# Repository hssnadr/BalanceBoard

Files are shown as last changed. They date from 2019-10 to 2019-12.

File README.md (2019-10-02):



# BalanceBoard
The Balance board demo project is part of the Movuino project: http://www.movuino.com/  
Project presentation: http://www.movuino.com/index.php/portfolio/balance-board/

## Set-up
* Download and install Movuino/Movuina: www.movuino.com
* Follow the tutorial to receive the data from your sensor: http://www.movuino.com/index.php/quick-start/
* Install PureData Vanilla from: www.puredata.info
* Into PureData, go to: Help/Find Externals
* Search for "MrPeach" library, it's used to receive the messages from Movuina through OSC communication
* Install and restart PureData
* Launch the BalanceBoard_Application.pd patch

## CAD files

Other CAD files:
01_MakingRessources/CAO/MovuinoCase_WorkFile.CATPart

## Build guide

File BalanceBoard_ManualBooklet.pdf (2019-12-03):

# BALANCE BOARD

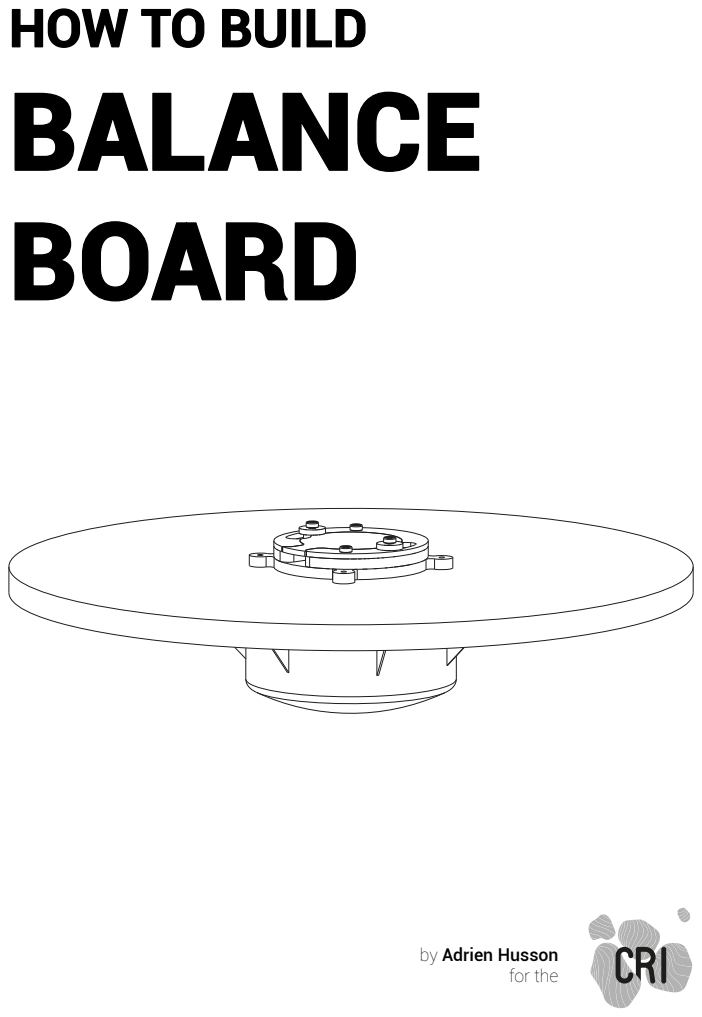
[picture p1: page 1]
for the

HOW TO BUILD

by Adrien Husson

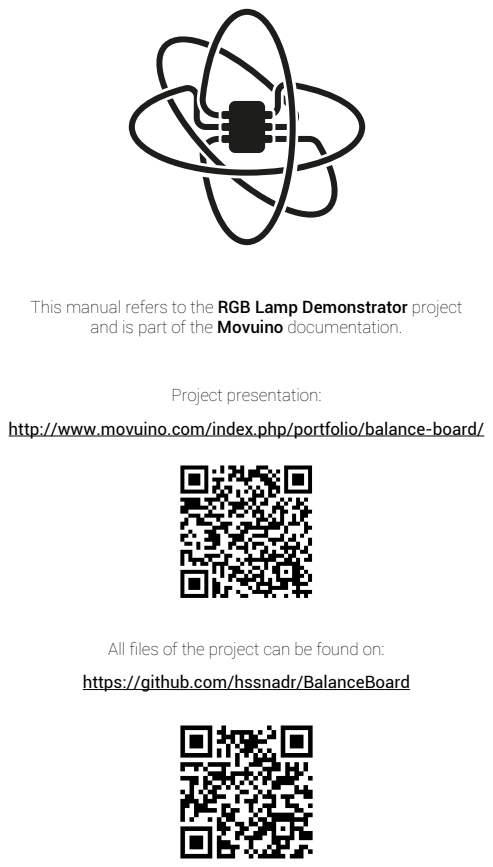
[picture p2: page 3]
Project presentation:

This manual refers to the RGB Lamp Demonstrator project
and is part of the Movuino documentation.

http://www.movuino.com/index.php/portfolio/balance-board/

All files of the project can be found on:
https://github.com/hssnadr/BalanceBoard

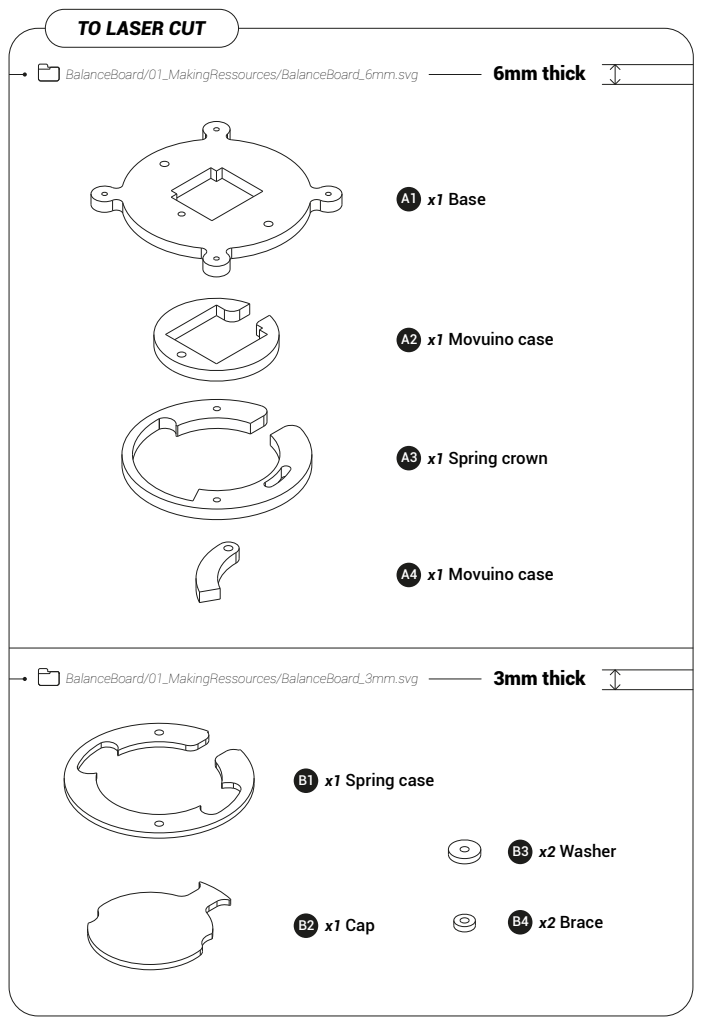
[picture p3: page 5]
3mm thick; BalanceBoard/01_MakingRessources/BalanceBoard_6mm.svg; A1 x1 Base; A2 x1 Movuino case; A4 x1 Movuino case; B1 x1 Spring case; B3 x2 Washer; B2 x1 Cap; B4 x2 Brace; A3 x1 Spring crown; 6mm thick; BalanceBoard/01_MakingRessources/BalanceBoard_3mm.svg

TO LASER CUT

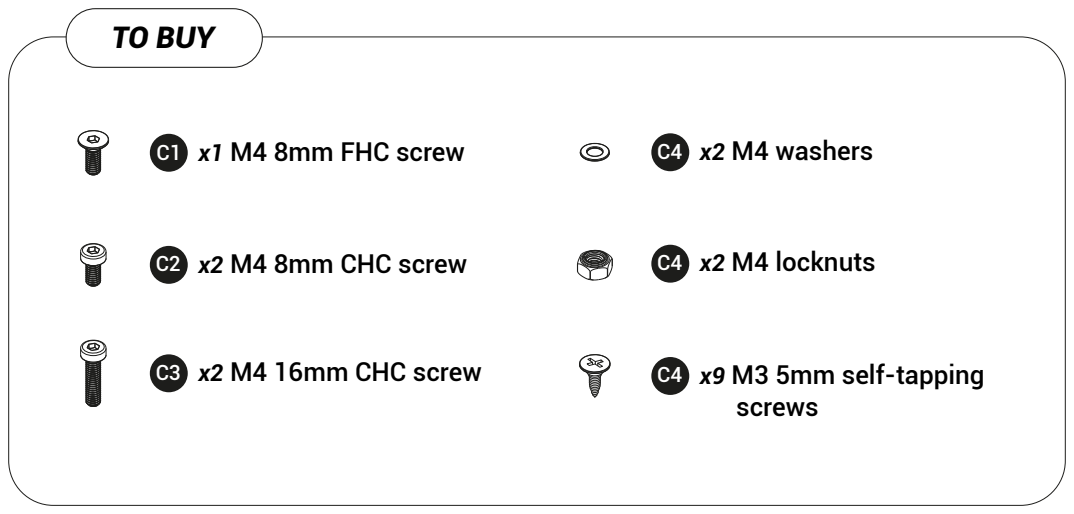
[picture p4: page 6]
TO BUY; C1 x1 M4 8mm FHC screw; C2 x2 M4 8mm CHC screw; C3 x2 M4 16mm CHC screw; C4 x2 M4 washers; C4 x2 M4 locknuts; x9 M3 5mm self-tapping screws

# ASSEMBLY

1

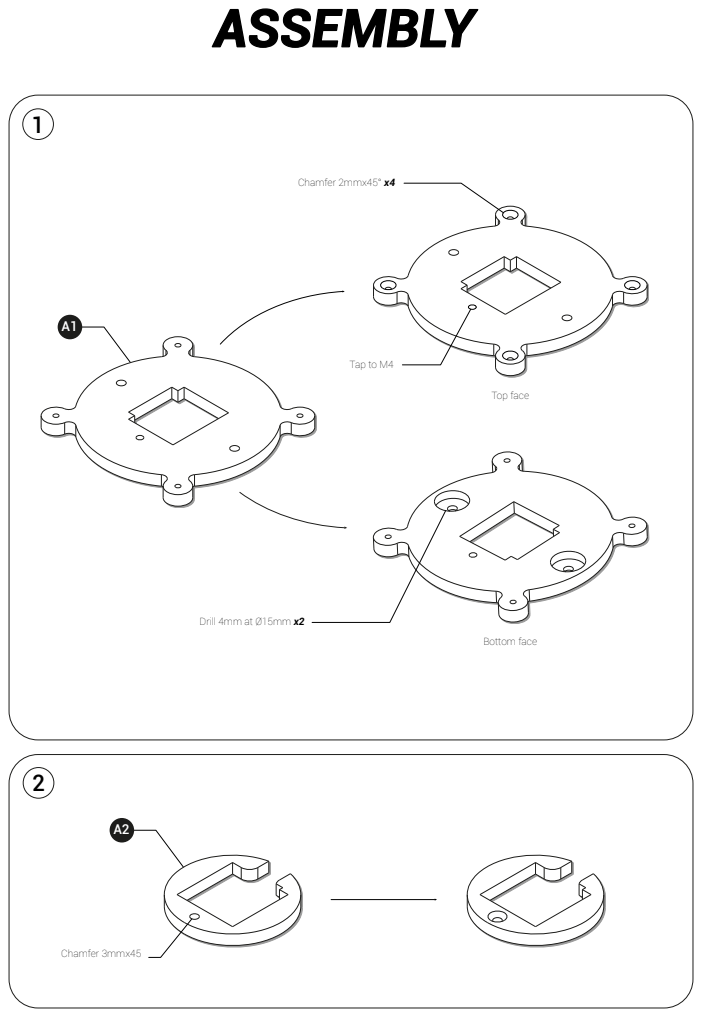
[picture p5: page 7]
Chamfer 2mmx45° x4; Top face; Bottom face; Tap to M4; Chamfer 3mmx45; Drill 4mm at Ø15mm x2

3

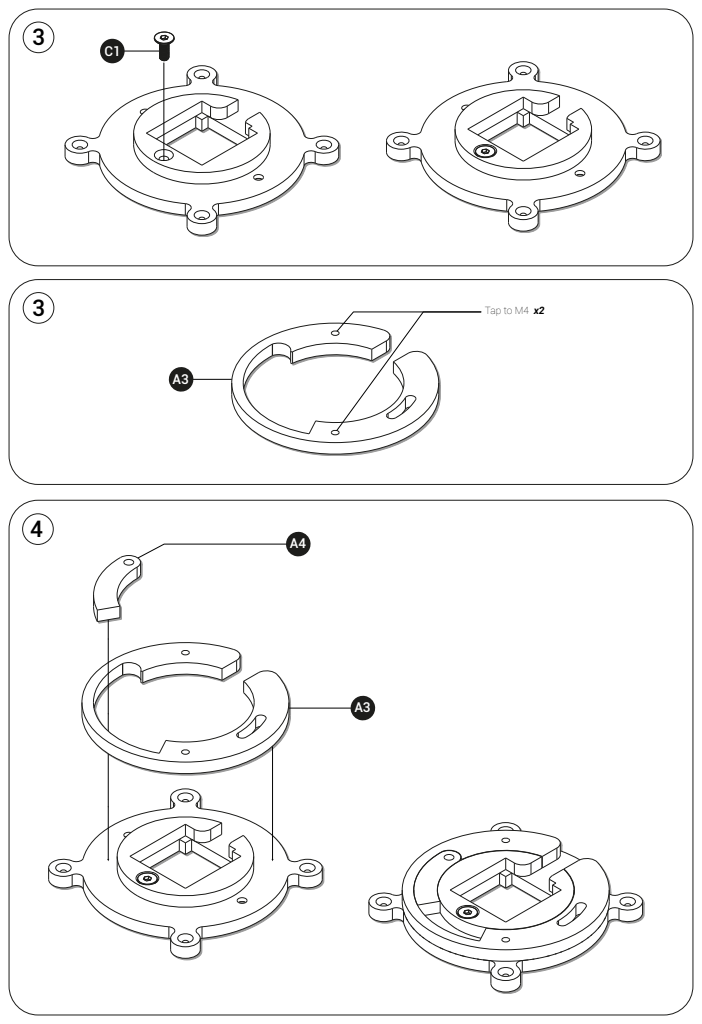
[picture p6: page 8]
Tap to M4 x2

5

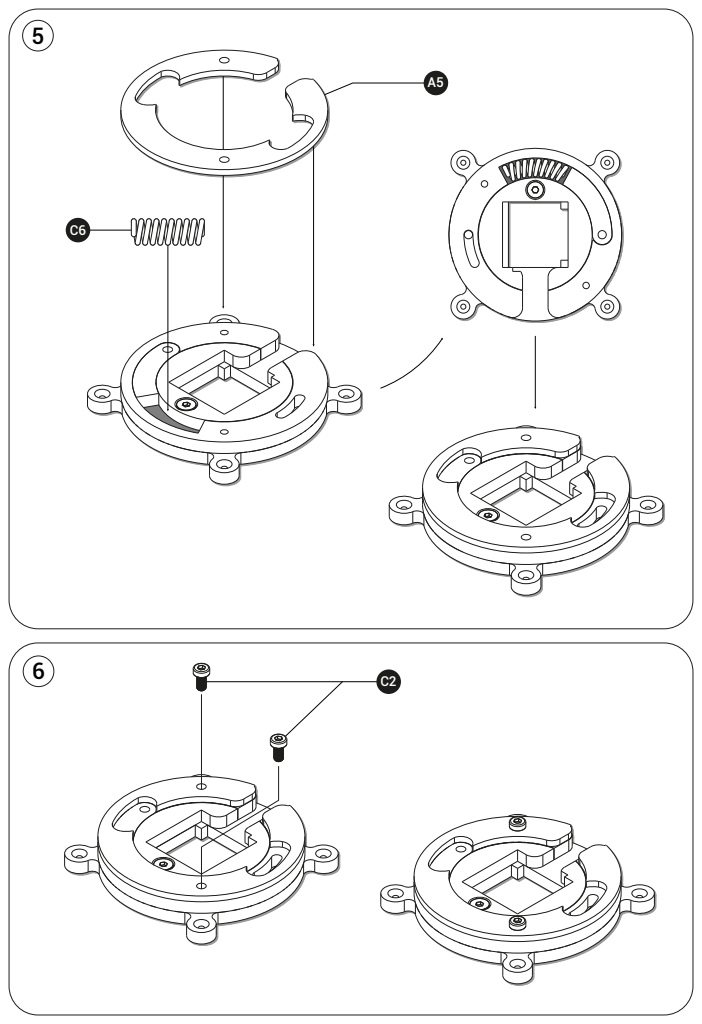
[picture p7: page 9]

7

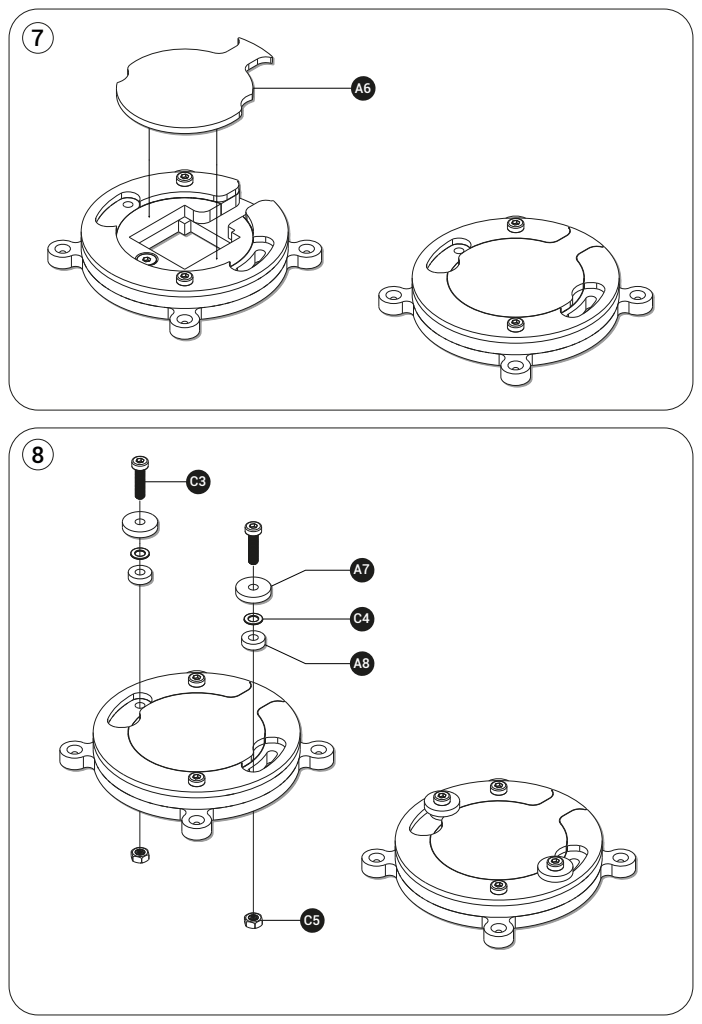
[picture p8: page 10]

9

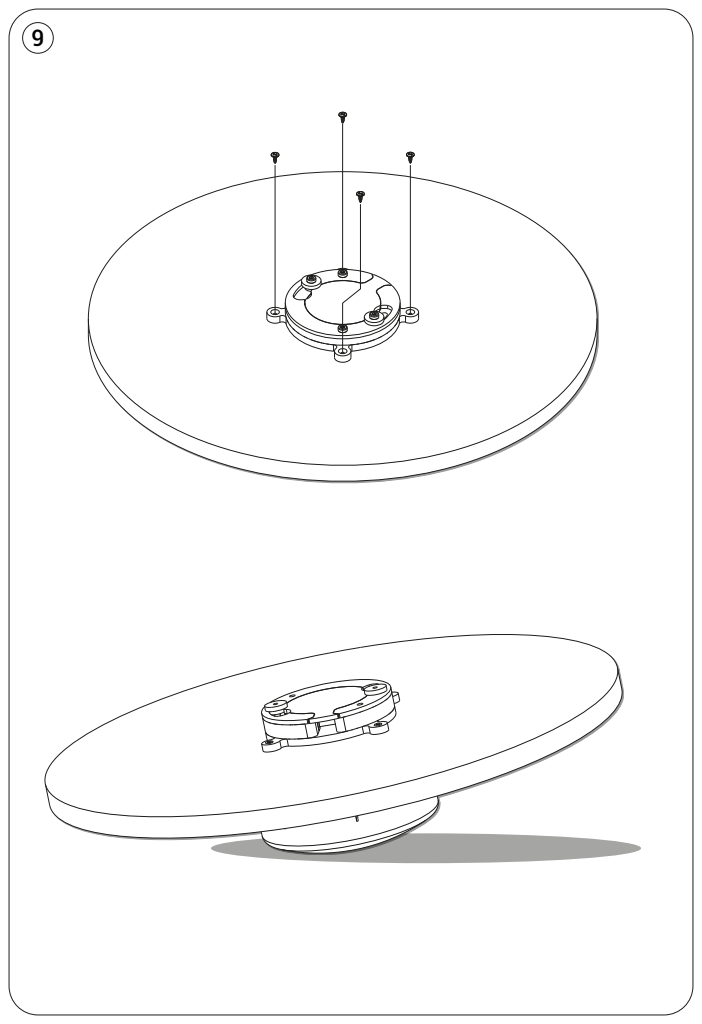
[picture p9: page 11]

1

# SET-UP

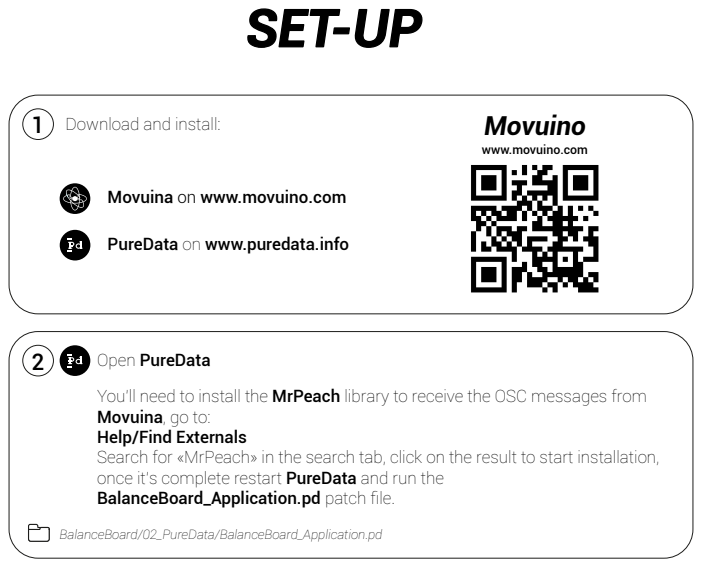
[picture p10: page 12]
Open PureData; BalanceBoard/02_PureData/BalanceBoard_Application.pd; Movuino

Download and install:

www.movuino.com

Movuina on www.movuino.com

PureData on www.puredata.info

You’ll need to install the MrPeach library to receive the OSC messages from
Movuina, go to:
Help/Find Externals
Search for «MrPeach» in the search tab, click on the result to start installation,
once it’s complete restart PureData and run the
BalanceBoard_Application.pd patch file.

3 Launch Movuina and set-up by following the Quick Start tutorial

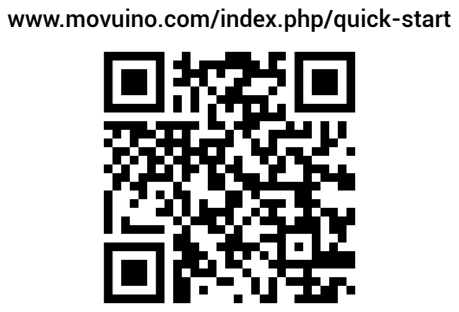
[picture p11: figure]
www.movuino.com/index.php/quick-start

Once its done, you can directly receive the acceleration data sensed by the Movuino (or Streamo) into the PureData patch. There the data are

## Quick Start

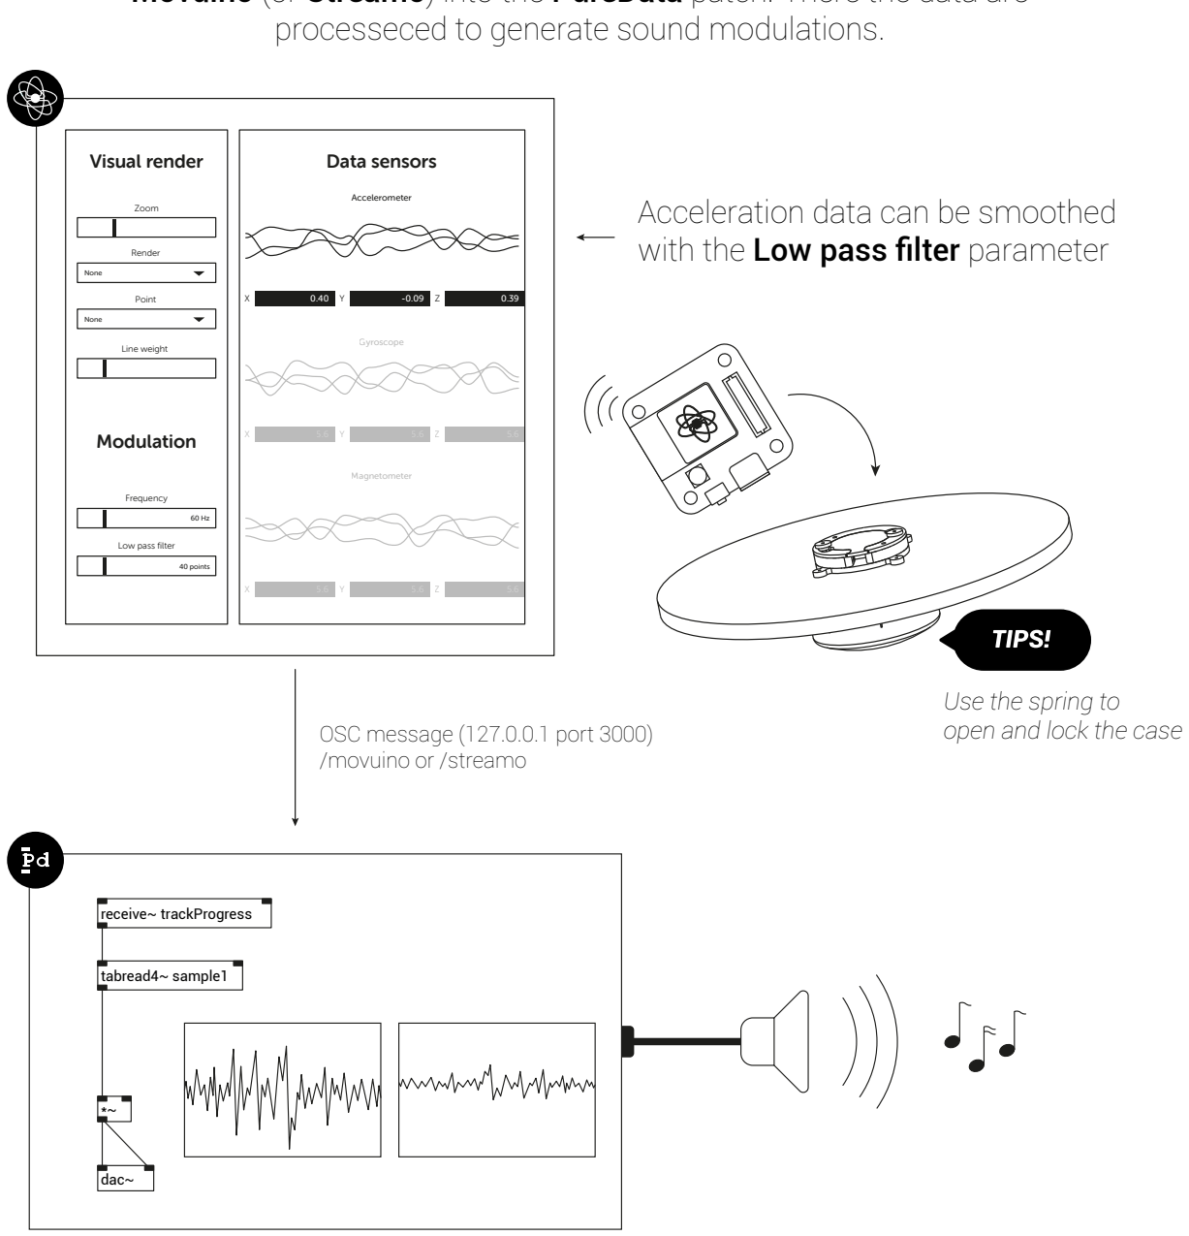
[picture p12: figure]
processeced to generate sound modulations.; Acceleration data can be smoothed with the Low pass filter parameter; OSC message (127.0.0.1 port 3000) /movuino or /streamo; None; Render; Point; Zoom; Frequency; Line weight; Accelerometer; Gyroscope; Magnetometer; Modulation; Visual render; Data sensors; Low pass filter; 40 points; dac~; tabread4~ sample1; receive~ trackProgress; Use the spring to open and lock the case

# PRINCIPLE

m

x

x
eq k

# d²x m = ΣFext dt²

# d²x m = k∆x - mg dt²

To sense acceleration, the accelerometers are based on the Newton’s 2nd law, this law highlights a direct link between the size of a spring and the acceleration of its mass.

On this extremely simplified view of the electronic embedded in an accelerometer, you notice the sensor will be affected by the gravity in addition to its own acceleration. Most of the time this extra data is a noise, but in our case this will allow us to get the orientation of the Movuino simply by reading the acceleration data on the XY plan. The way the Movuino is placed on the balance plate minimizes its own acceleration. Thus, the main acceleration component sensed is the effect of gravity. Smoothing the data with the low pass filter enhance this principle.

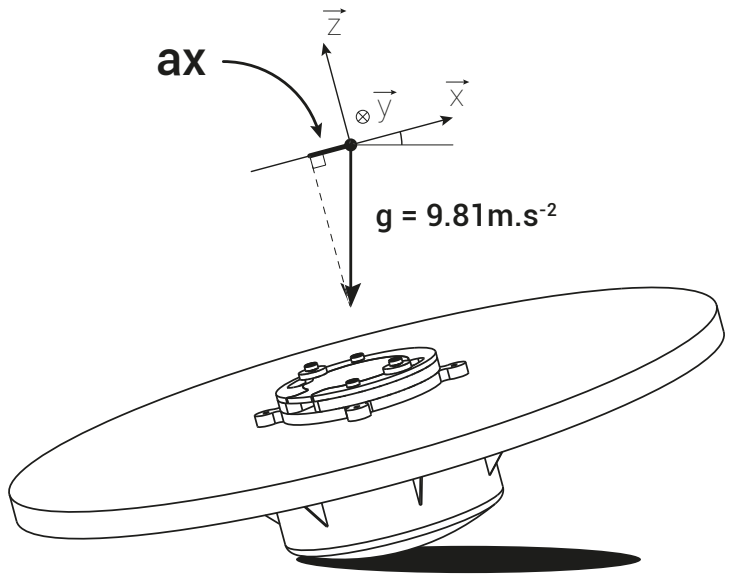
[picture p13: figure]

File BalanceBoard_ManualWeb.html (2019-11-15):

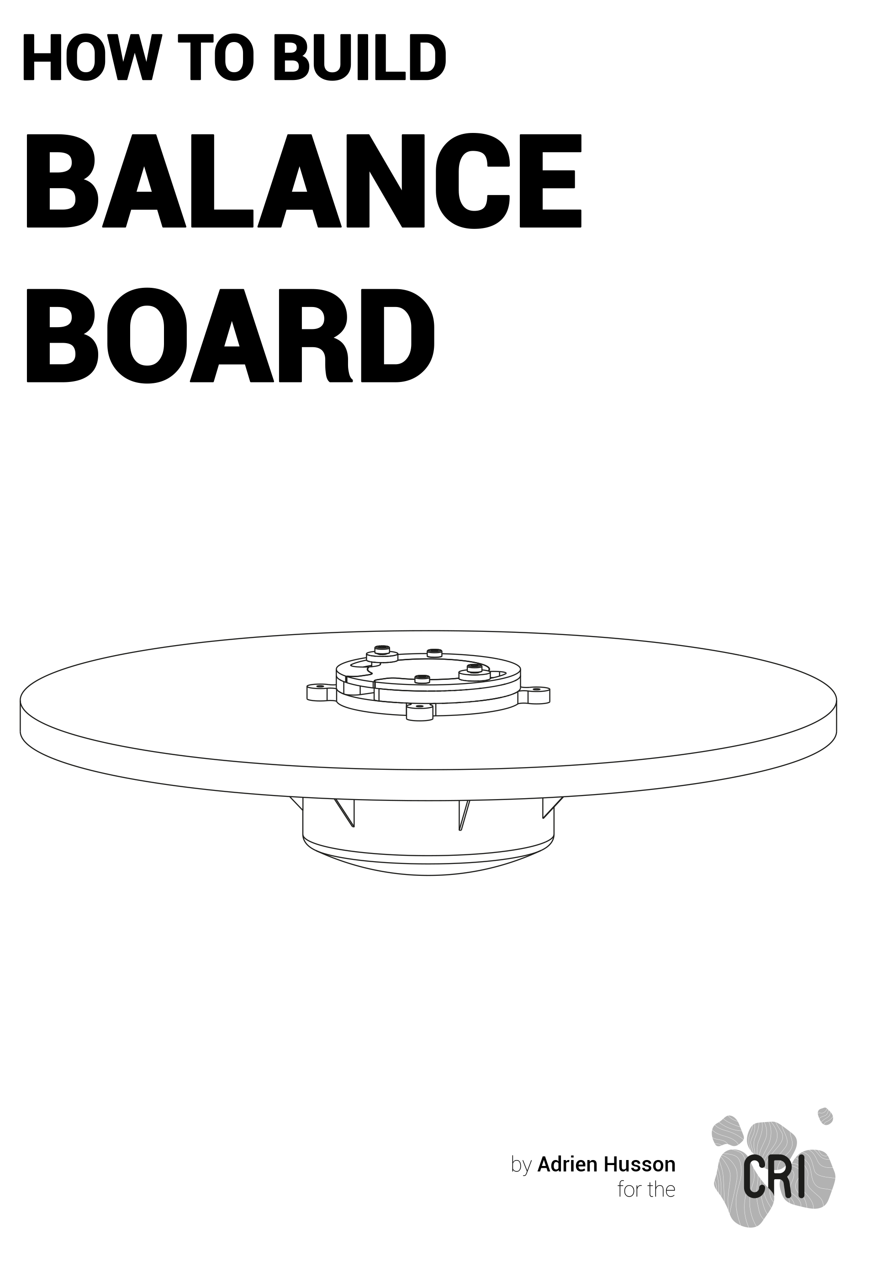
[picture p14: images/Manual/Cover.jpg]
Cover


Download manual (https://github.com/hssnadr/BalanceBoard/raw/master/BalanceBoard_ManualBooklet.pdf)

### Furnitures

Get all the files you'll need and start following the tutorial

Download ressources (https://github.com/hssnadr/BalanceBoard/archive/master.zip) See on Github (https://github.com/hssnadr/BalanceBoard)

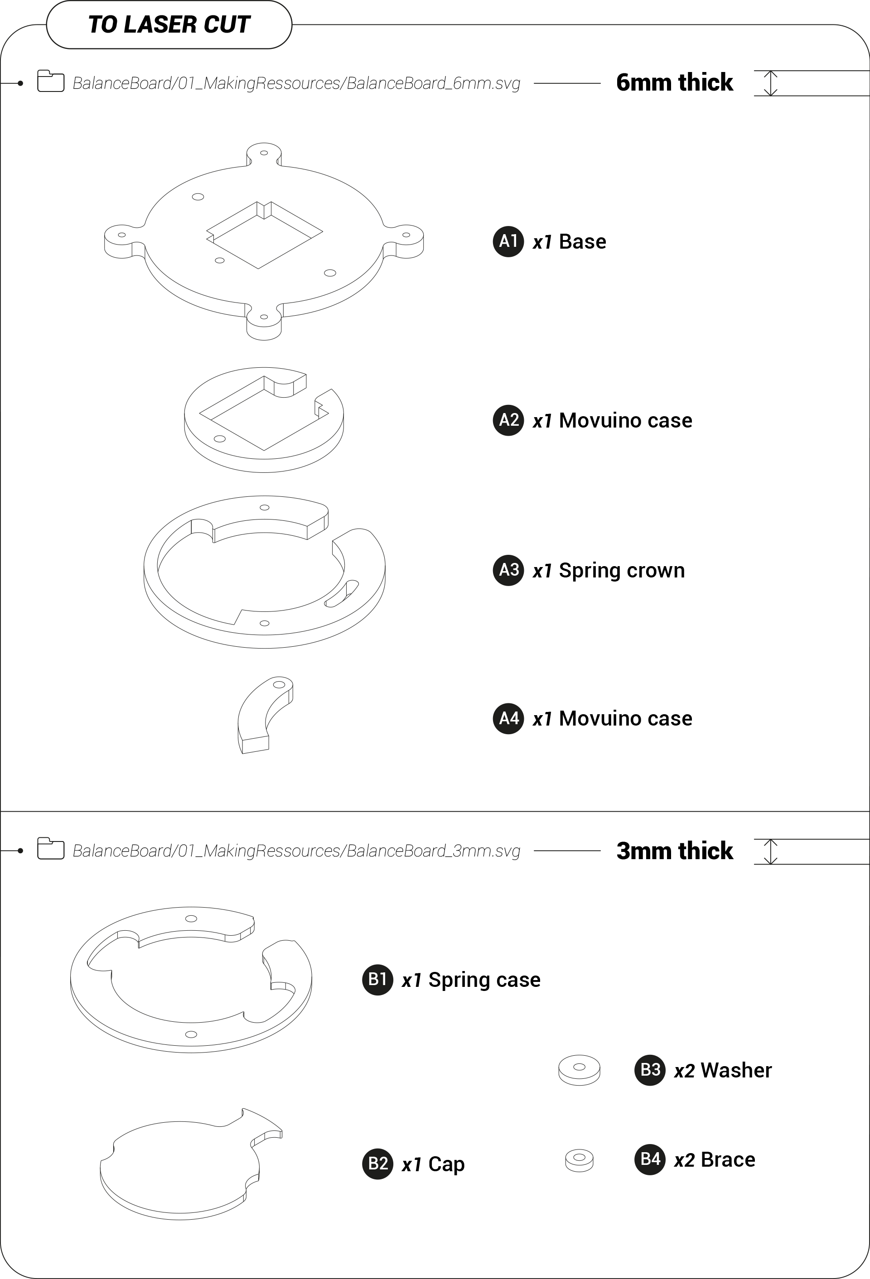
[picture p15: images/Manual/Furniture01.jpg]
Furniture01
 Furniture02

### Assembly

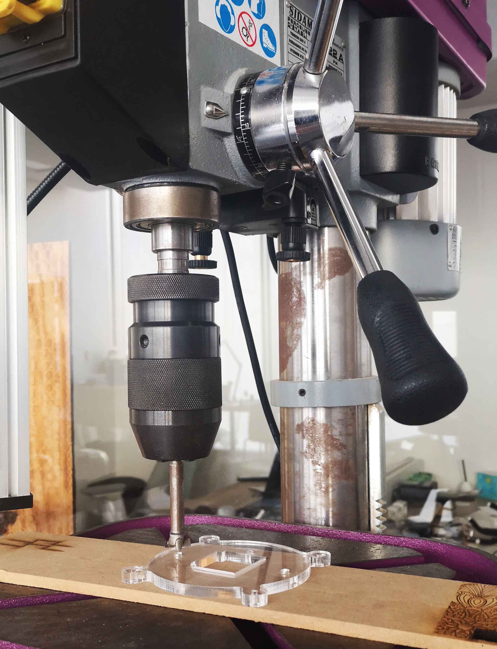
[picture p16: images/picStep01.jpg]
picStep01
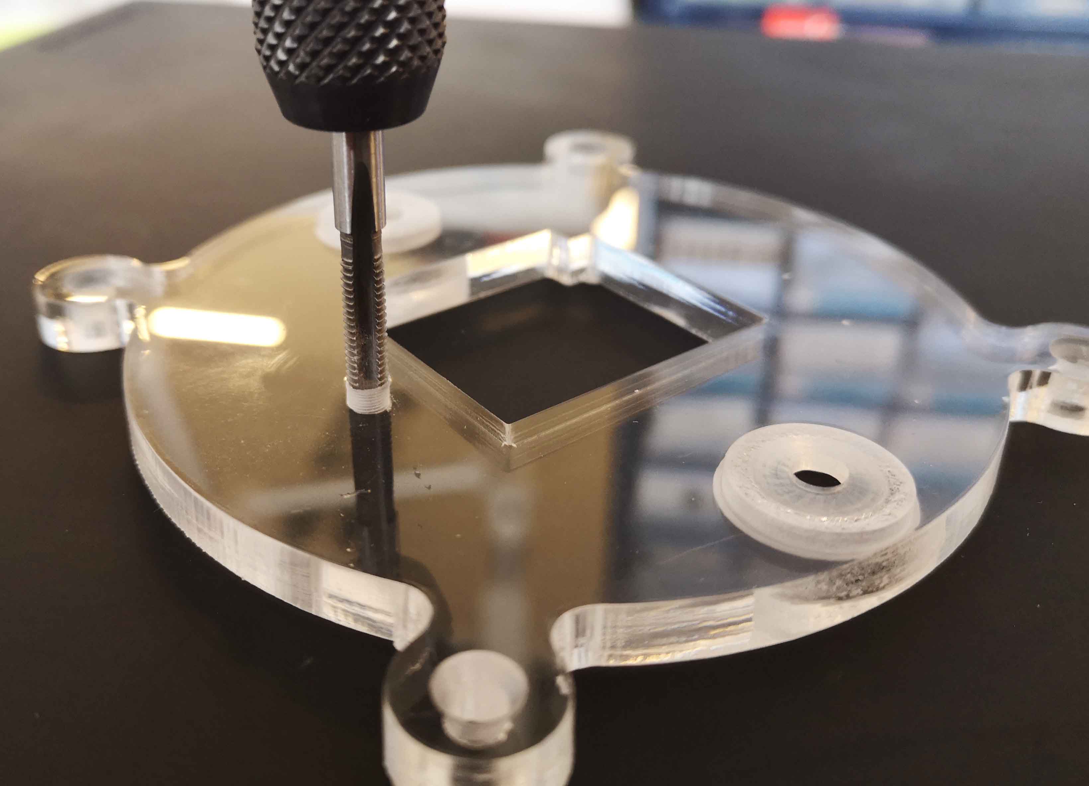
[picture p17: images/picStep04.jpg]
picStep04
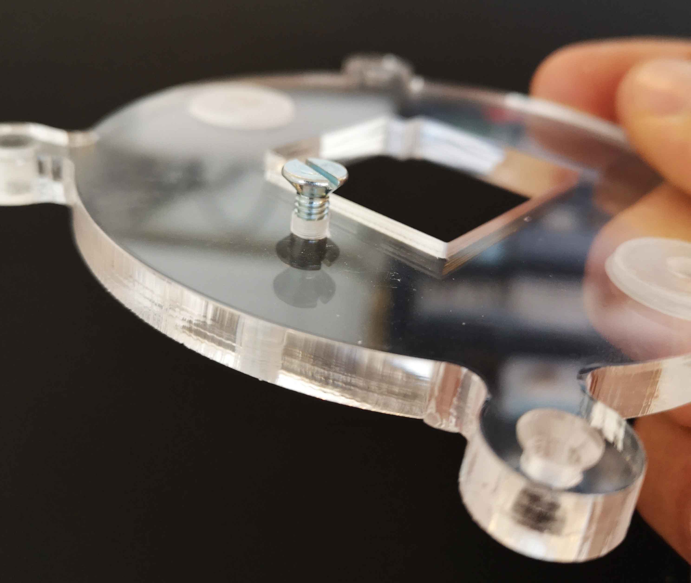
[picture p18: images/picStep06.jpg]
picStep06
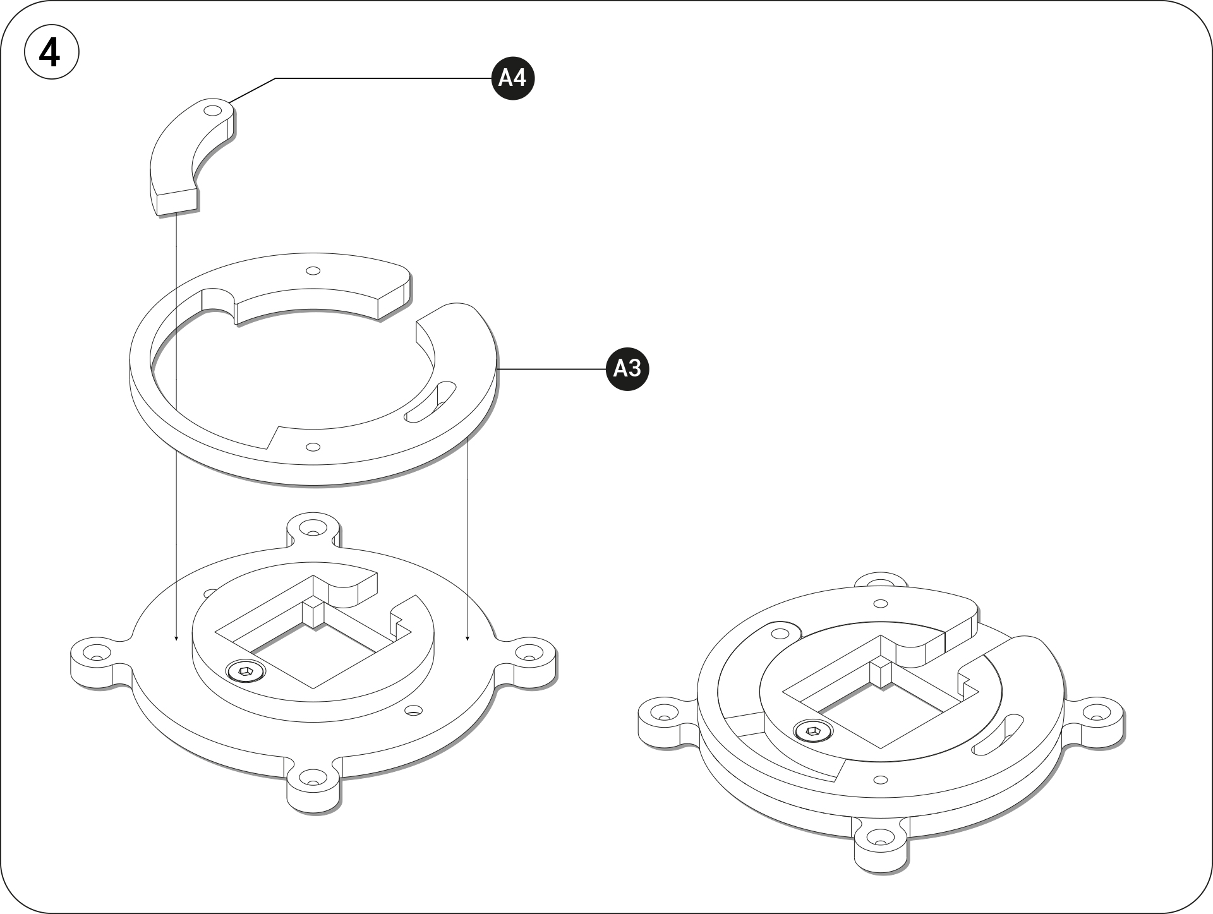
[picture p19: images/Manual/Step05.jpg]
Step05
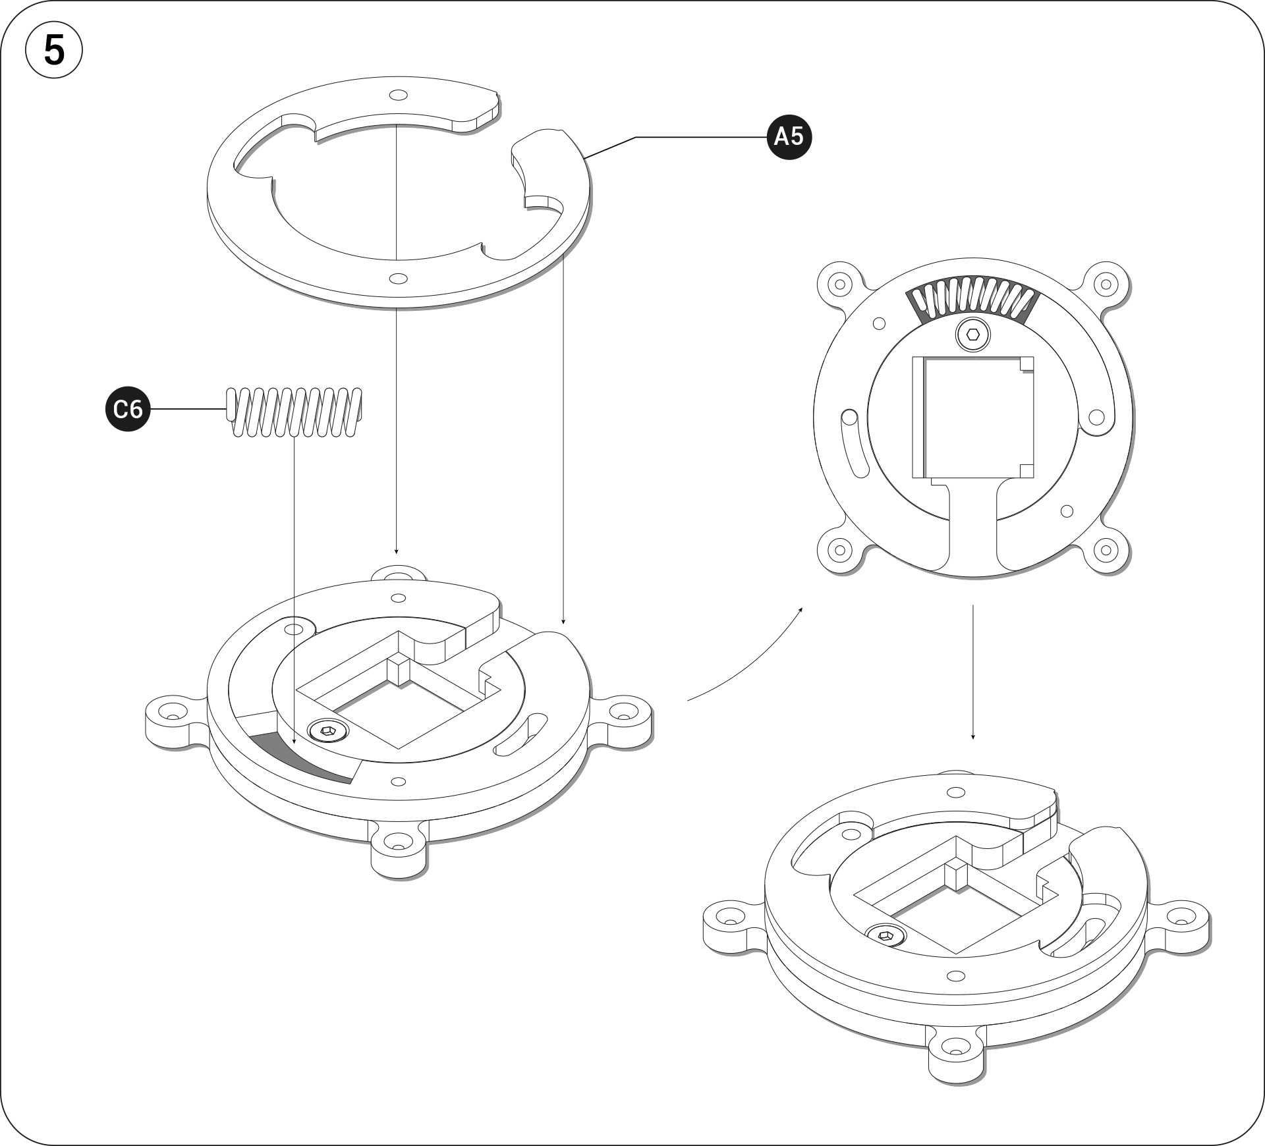
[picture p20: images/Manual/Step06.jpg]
Step06
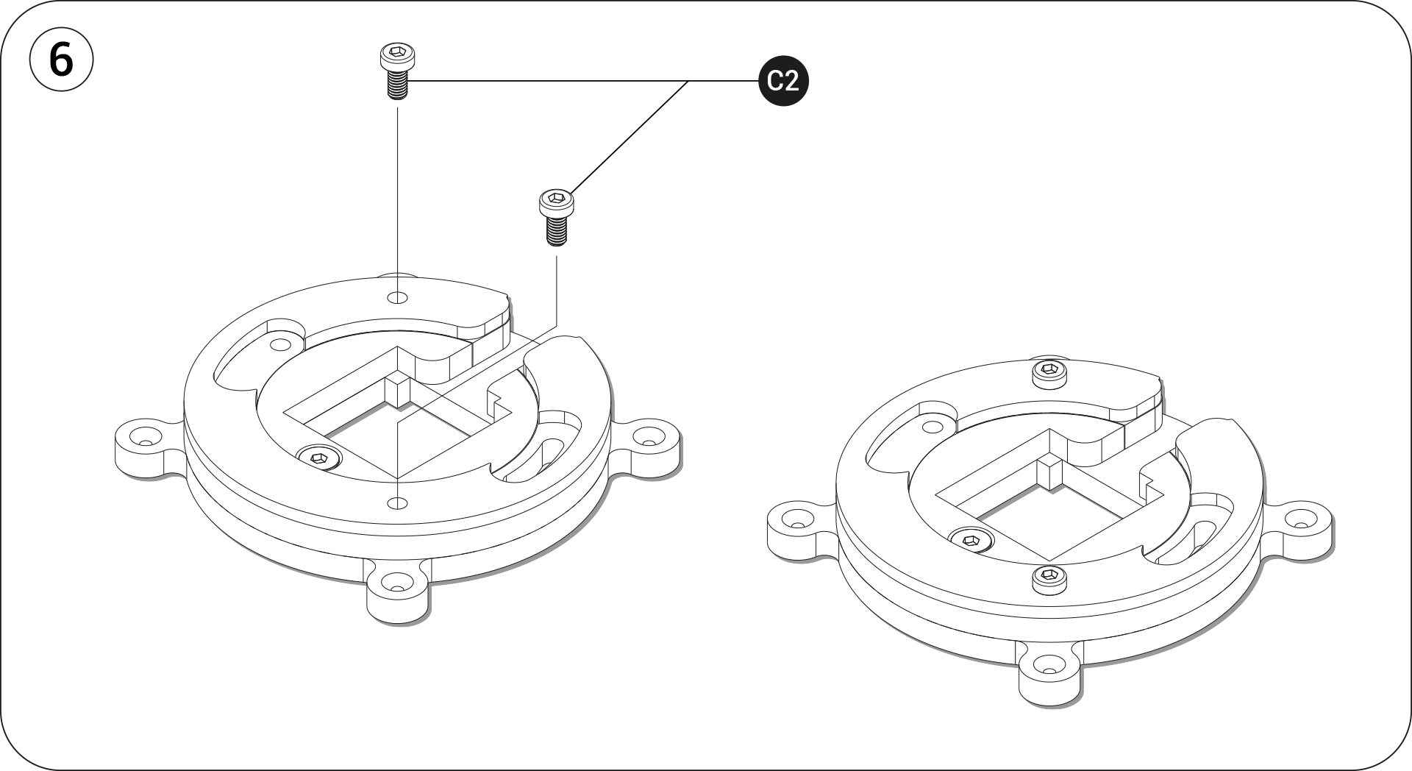
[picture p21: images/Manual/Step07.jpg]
Step07
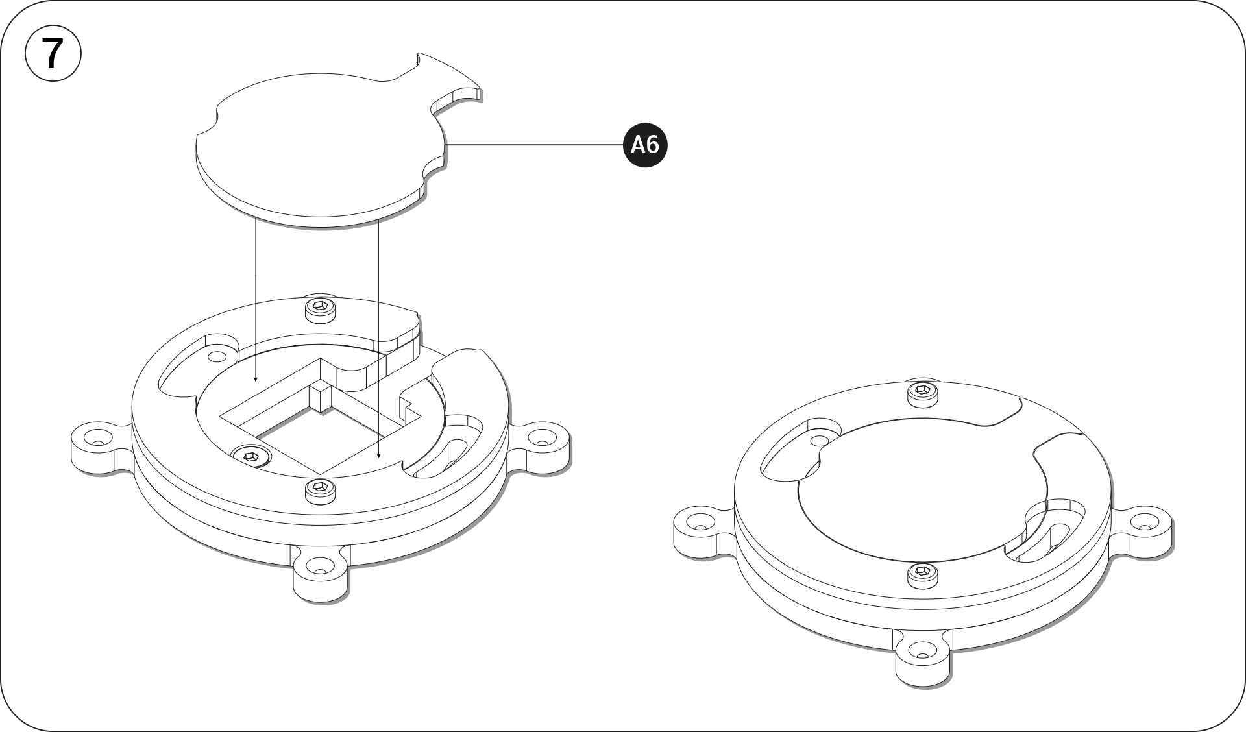
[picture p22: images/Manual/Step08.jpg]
Step08
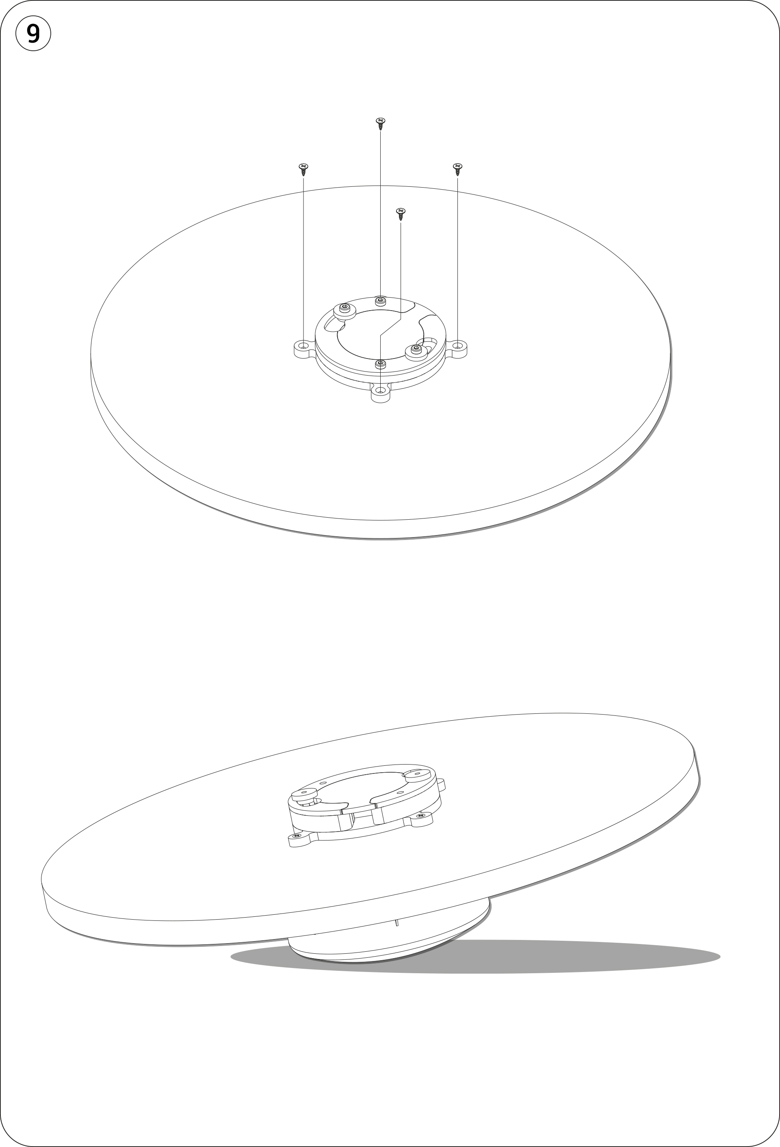
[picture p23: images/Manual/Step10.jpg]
Step10
Step01  picStep02 picStep03  picStep05  Step02 Step03 Step04     Step09 

### Set-Up

PictoArduino

Download and install Pure Data (Vanilla) (http://puredata.info/downloads)

1. Open it, you’ll need to install the MrPeach library to receive the OSC messages from Movuina, go to: Help/Find Externals
2. Search for «MrPeach» in the search tab, click on the result to start installation, once it’s complete restart PureData and run the BalanceBoard_Application.pd patch file.

PictoFolder

BalanceBoard/02_PureData/ (https://github.com/hssnadr/BalanceBoard/tree/master/02_PureData)

PictoProcessing

Download and install Movuina (http://www.movuino.com#dlmovuina)

Launch Movuina and set-up by following the Quick Start tutorial

Quick start tutorial (http://www.movuino.com/index.php/quick-start/)

Once its done, you can directly receive the acceleration data sensed by the Movuino (or Streamo) into the PureData patch. There the data are processeced to generate sound modulations.

SetUp

### Principle

To sense acceleration, the accelerometers are based on the Newton's 2nd law, this law highlights a direct link between the size of a spring and the acceleration of its mass.

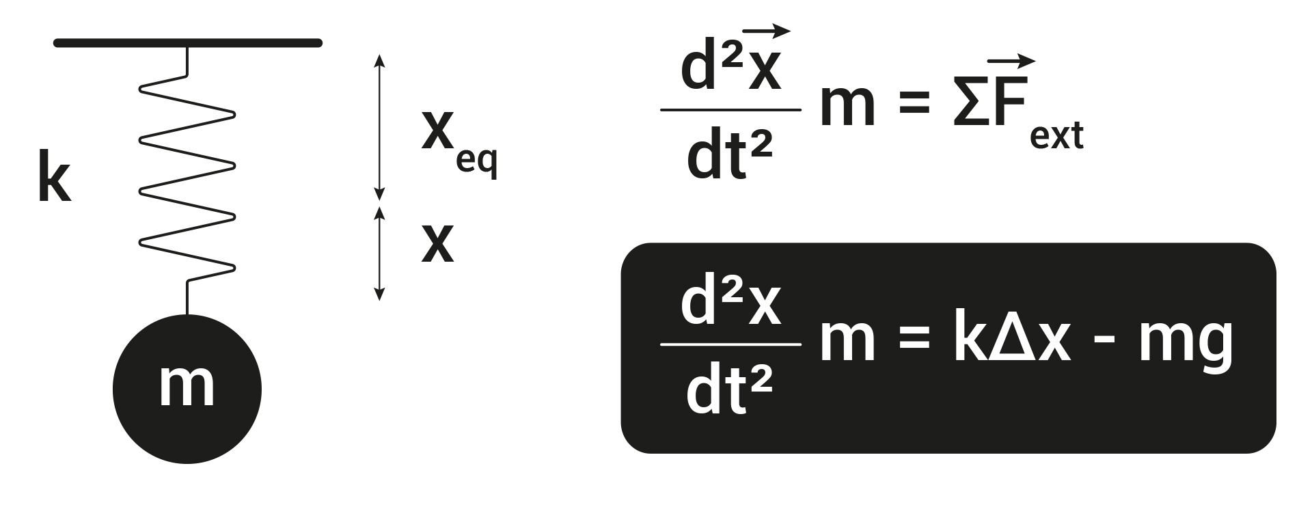
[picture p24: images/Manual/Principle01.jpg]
Principle01


On this extremely simplified view of the electronic embedded in an accelerometer, you notice the sensor will be affected by the gravity in addition to its own acceleration.

Most of the time this extra data is a noise, but in our case this will allow us to get the orientation of the Movuino simply by reading the acceleration data on the XY plan.

The way the Movuino is placed on the balance plate minimizes its own acceleration. Thus, the main acceleration component sensed is the effect of gravity. Smoothing the data with the low pass filter enhance this principle.

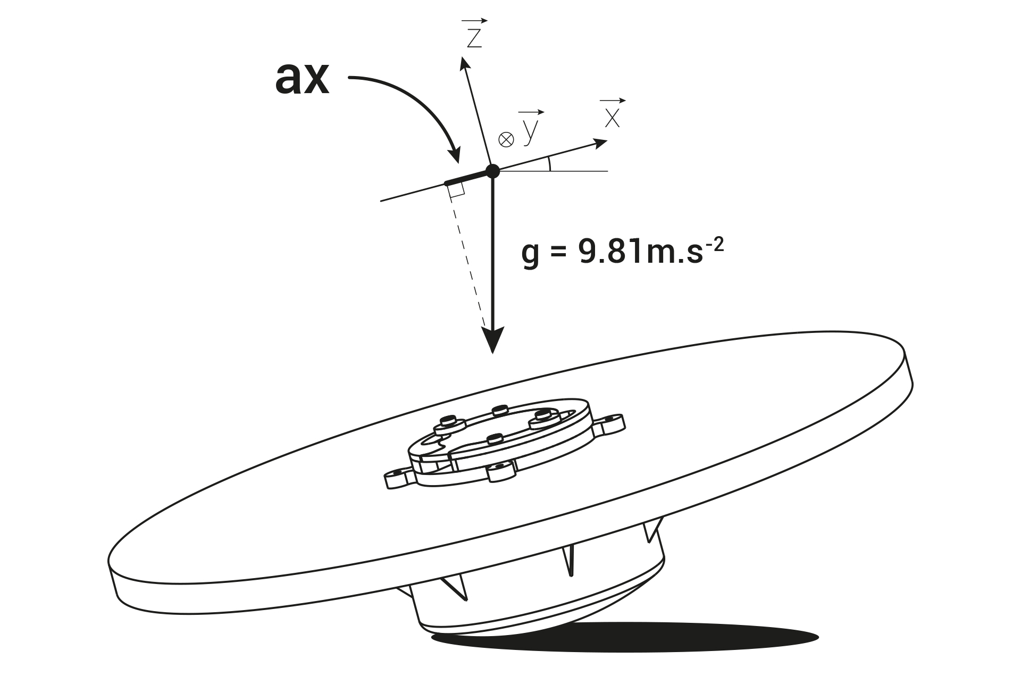
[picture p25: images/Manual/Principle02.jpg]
Principle02


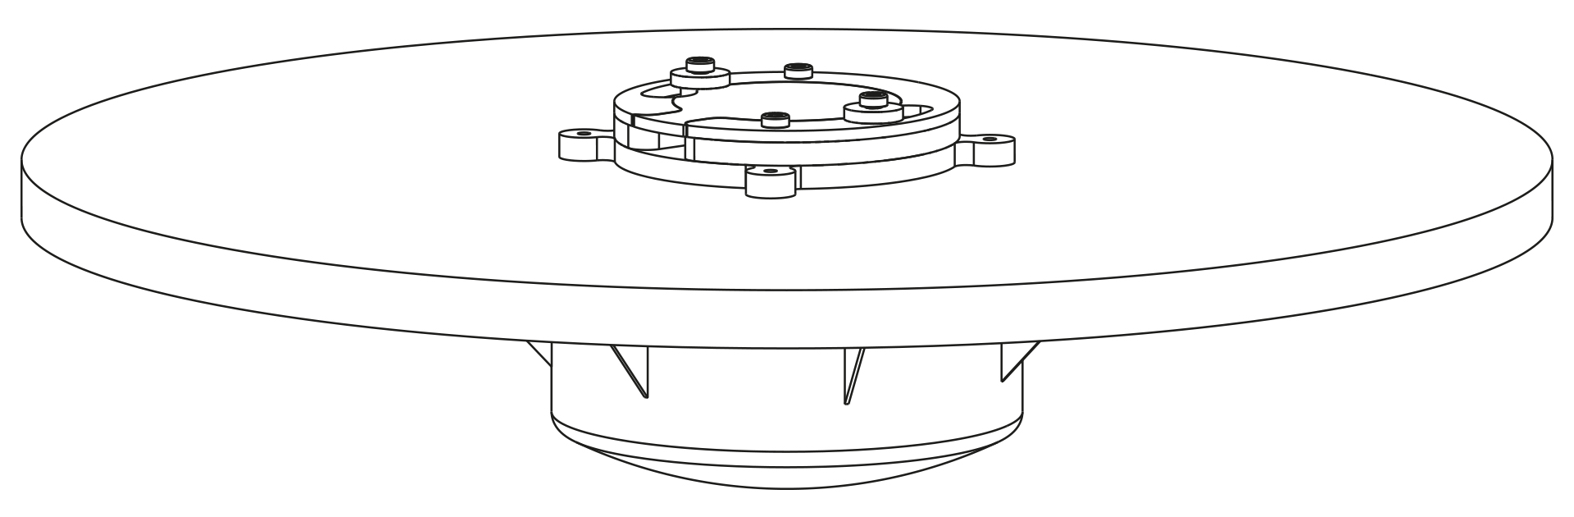
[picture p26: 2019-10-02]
images/Manual/BalanceBoard.jpg

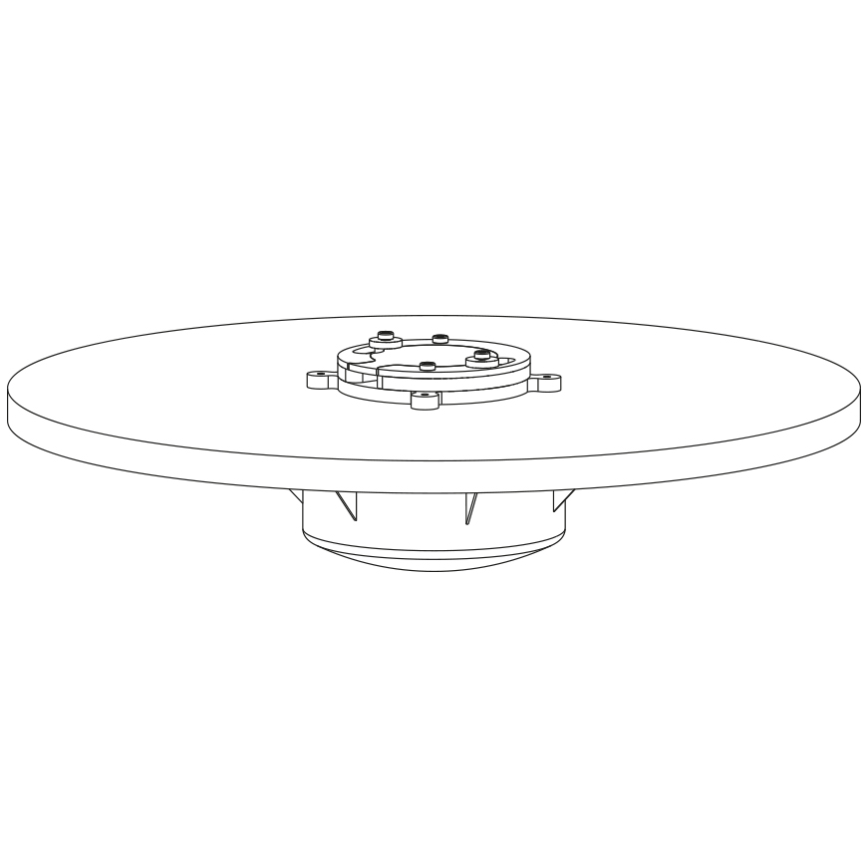
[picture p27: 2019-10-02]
images/Manual/BalanceBoard_preview.jpg

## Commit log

2019-08-22 laser cut 3mm
2019-08-23 update covers
    [3mm_Covers.dwg, Movuino_Plate_v2.CATPart]
2019-08-29 update CAO
    [Movuino_Plate_v3.CATPart]
2019-09-11 update manual
    [BalanceBoard_Assembly.CATProduct, Crown.CATPart, MovuinoCase_WorkFile.CATPart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]
2019-09-18 Manual v1
    [BalanceBoard_Assembly.CATProduct, Base.CATPart, MovuinoCase_WorkFile.CATPart]
2019-09-19 laser cut files
    [3mm_Brace.dwg, 3mm_Cap.dwg, 3mm_Cover.dwg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]
2019-09-19 base pure data
    [BalanceBoard_Assembly.CATProduct, Drawing2.dwg]
2019-10-01 clean folder
    [BalanceBoard.CATPart, BalanceBoard_Assembly.CATProduct, Base.CATPart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]
